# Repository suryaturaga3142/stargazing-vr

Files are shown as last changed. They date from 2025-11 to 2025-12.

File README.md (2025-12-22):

# Stargazer VR

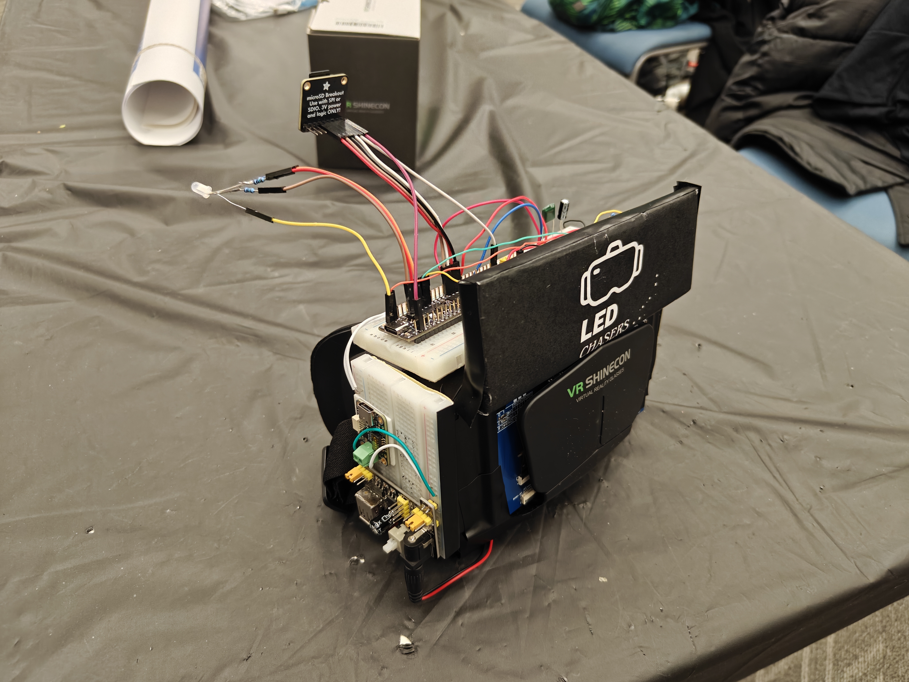
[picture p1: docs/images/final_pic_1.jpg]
Project Banner / Hero Image

*A high-performance, standalone VR headset powered by the RP2350 that renders real-time star constellations based on precise geolocation and orientation.*

---

## 📖 Introduction

Light pollution is a problem not many people talk about. We wanted to shed light on this issue (pun intended), so we decided to build a VR headset that let the user see the night sky at the comfort of their home. 

This project is a wearable headset with an RP2350 microcontroller and two 3.5" TFT LCD displays to display stars and constellations in the sky, in the direction of the viewer sight. It uses a BNO085 IMU to track the user movements, a NEO-M10 GPS module to obtain present location, date, and time, and an SD Card to store a large catalog of star location data in a binary file.

### ⭐ Spotlight

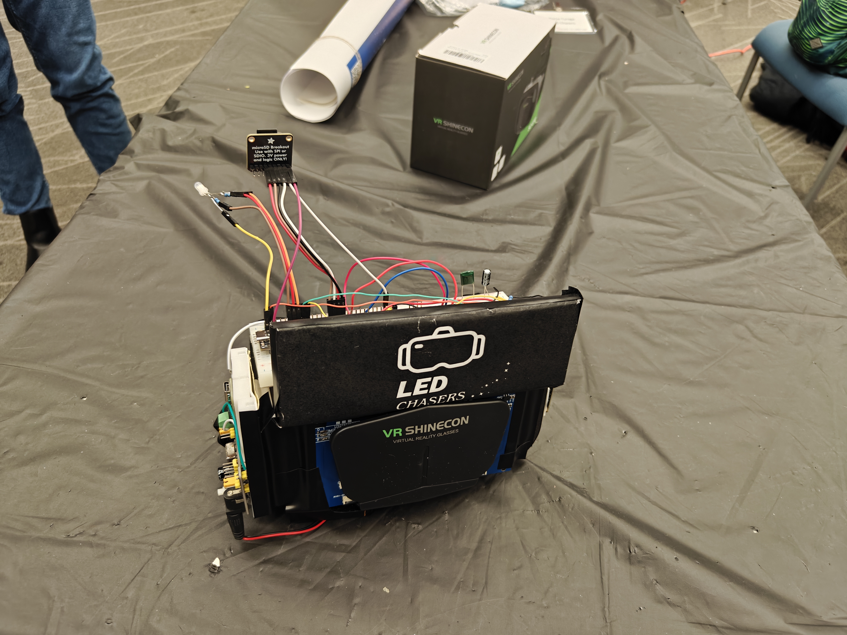
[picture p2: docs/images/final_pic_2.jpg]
Spotlight 1

*VR Headset assembled with a case, breadboards, and standard parts.*

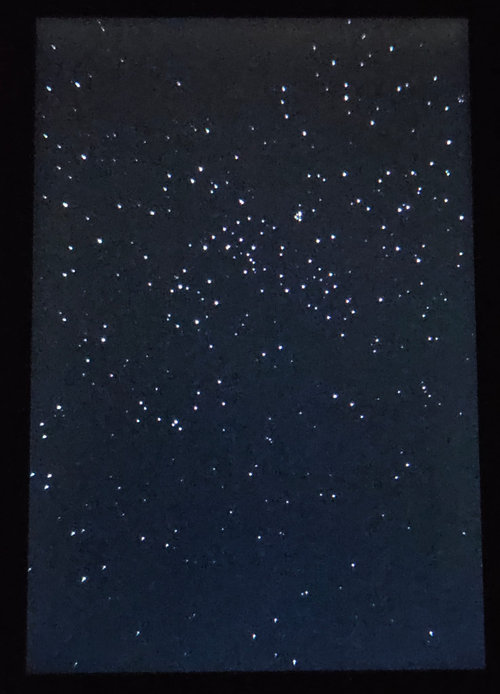
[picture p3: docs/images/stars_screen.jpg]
Spotlight 2

*View from a single screen during operation.*

Full View (https://youtu.be/E_Z8thj5-Y4?si=hsxMM6rmYNDNSfJs)

*360 Degree View of the Headset*

---

## 📑 Table of Contents

Our Story

- [Features](#-features)
- [Instructions for Usage](#-instructions-for-usage)
- [Software Developement](#-software-development)
  - [The Rendering Pipeline](#-the-rendering-pipeline)
  - [Side Quest 1: Scripting](#-side-quest-1-scripting)
  - [Optimizations](#-optimizations)
- [Hardware Building](#-hardware-building)
  - [The Physical Design](#-the-physical-design)
  - [So many issues!](#-so-many-issues)
  - [Side Quest 2: PCB Design](#-side-quest-2-pcb-design)
  - [Putting it all together](#-putting-it-all-together)
- [Closing Thoughts](#-closing-thoughts)

## 🚀 Features

The headset runs on a standard 9V battery, has two 3.5" TFT LCDs that display stars in front of the user with a 100 degree FOV. A single RGB LED is used to indicate the state of the VR Headset: booting, running, paused, critical error, etc. There are 3 buttons used to control the headset program flow. The Tare button recalibrates the IMU to face true North, the GPS toggle button switches between using real time GPS data and an in-built location and time (Purdue J2000), and the Pause/Play button does exactly that.

A single microSD card containing the required binary file format of star data can be inserted. Upon startup, this data is loaded into the RAM and processed. The catalog is limited to 15,000 stars. To produce the bin file, see [process_fits.py](data/scripts/process_fits.py), a script written to convert an fit file into the needed bin file.

The LCD Displays (ILI9486) as well as the microSD Card are controlled using SPI. The IMU (BNO085) is communicated with using I2C, more specifically SHTP. Finally, the GPS Module (Neo-M10) uses UART to transmit NMEA sentences.

---

Demo Video 1 (https://youtu.be/3412y5BKB1g?si=uu_Z9wU7jyXM4vg-)

*A short demonstration of the Headset working.*

Demo Video 2 (https://youtu.be/89O6f0i35UU?si=O_-78V77JQVSeXiZ)

*A demonstration of the UI of the headset.*

---

## 📃 Instructions for Usage

If wiring up on a breadboard, refer to the KiCad schematic for exact resistor values to use for the RGB LED, and connections to configure the IMU in I2C mode. Everything else works as it should assuming the use of breakout boards. Any standard LDO can be used to provide the 5V supply from the 9V battery. 

> [!WARNING]
> Do not connect a 3V3 output of your MCU to the LCDs! SST drivers have boost converters in them (as you should if you're implementing your own driver) and the current draw from 2 LCDs is too much current draw. You need a seperate regulator to provide external 3V3 from your 9V external.

If you're using the PCB, it's a plug and play. It needs the Adafruit BNO085 IMU breakout board (they were out of stock when this was designed). The PCB also makes use of 16 bit 8080 for the displays, making it significantly faster. Instead of a 9V battery, it will need a LiPo battery rated for above 1A. It can be charged with a wall charger, and programmed using a Pico probe.

---

## 🖥️ Software Development

We started with the software. Before wiring anything up, we began testing our design flow of using interrupts for timers, PWM, and GPIO. Then we went on to the more complex aspects like the communication with peripherals.

### 🚄 The Rendering Pipeline

The critical path is IMU to display, and it runs at 200Hz. The IMU generates in interrupt, which triggers main to read data, process it, find the final rotation, generate the star list, and draw/erase the display. Everything else, such as state setting, GPS reading, IMU taring, etc happen in the remaining 5ms between reads. 

The watchdog in the MCU is set to 1000ms and cleared every 200ms, so if there's a deadlock (especially an issue with the GPS), the system reboots.

### 🎬 Side Quest 1: Scripting

Python scripts were the method we used to get stuff done.

[process_fits.py](data/scripts/process_fits.py) is the most critical one. We used it to generate the needed binary file from a heavy fit file. Used ```astropy```.

[game_rot.py](data/scripts/game_rot.py) is more of an IMU debugging script. It reads game rotation vectors from the IMU and allows visualization of the data in 3D using ```pyqtgraph``` and ```PySide6```.

[see_stars.py](data/scripts/see_stars.py) is meant to test the sorting algorithm written to run on g++ in [test_buf_sort.cpp](data/scripts/test_buf_sort.cpp) by displaying the sorted data as patches on a 3D sphere. It's a neat visualization of how the data looks.

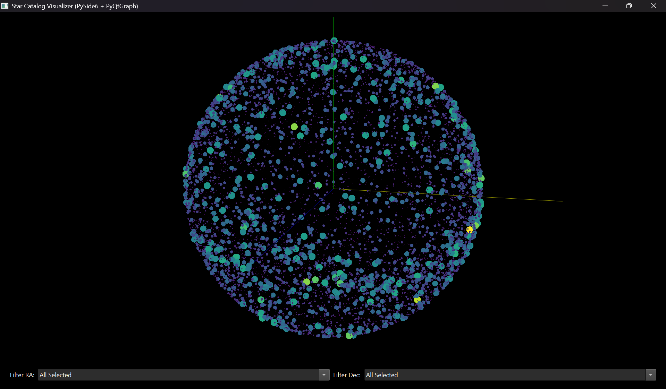
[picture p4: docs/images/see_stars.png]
Stars Visual

*Visualization of data sorted into 12 bins of Declination and 24 bins of Right Ascension.*

The remaining scripts were used to emulate the LCDs for debugging and calibrating purposes. They're more effective when you handwrite a small batch (~10) of test stars.

### 🪡 Optimizations

The first major optimization we used in this project was the use of quaternions for rotations. Instead of Euler angles, which are hard to visualize and are prone to gimbal lock, we used quaternions, which are 4D complex numbers, and are a completely neat set of mathematics immune to any edge cases. They literally describe rotations in the purest sense, with a single quaternion essentially behaving like a 3x3 rotation matrix meant to be applied on a 3x1 coordinate vector. Each of the 3 main factors - Location, Date/Time, and IMU vector - are all expressed as seperate quaternions, and combining them to obtain a single final rotation quaternions is akin to multiplying 3 matrices together!

$$ q_{final} = q_{IMU} \cdot q_{location} \cdot q_{time} $$

$$ v_{final} = q_{final} \cdot v_{J2000} \cdot q_{final}^{*} $$

Our next optimization was Spatial Culling, optimizing in what to do with this final rotation. Applying it to all stars only to then narrow down a 100 degree FOV would be far too expensive computationally. Instead, we applied the inverse rotation to the perspective vector, and then checked which set of stars could appear on screen. That's where the bin sorting came into play. The 288 patches were sorted based on RA and DEC, allowing easy access of patches to then apply the rotation to. 

Finally, we used double buffering to allow erasing of old stars and drawing of new ones together. Keeping this rate maxed out, it even created an unintentional twinkling effect of stars! It's not a bug, it's a feature.

---

## 🛠️ Hardware Building

While the code was being developed, stuff was getting wired up on the breadboard! Starting with the RGB LED, then moving to the IMU, GPS, SD Card, and finally, the displays. This was just the process of integration, of course. Everything software and hardware was being developed and tested slowly at the same time.

### The Physical Design

On the breadboard, there wasn't much to do. We simplified a lot of wiring by using breakout boards for all parts. Appropriate resistor sizes were chosen for the RGB LED and soldered. Everything else was just connected with regular wiring. The breadboard design was arguably the easiest part of this project. We got ourselves a 9V to breadboard supply board that provided the needed 5V and 3V3 supplies. That with a USB-C breakout was all we needed. Refer to [config.h](include/config.h) for exact connections for breadboarding. Remember, the PCB was different! Check the schematic for that.

### So many issues!

We initially tried to speed up graphics by using PIO to communicate with the LCDs through 16-bit 8080. Using long and noisy wires, this ended up being a bit of a mess.

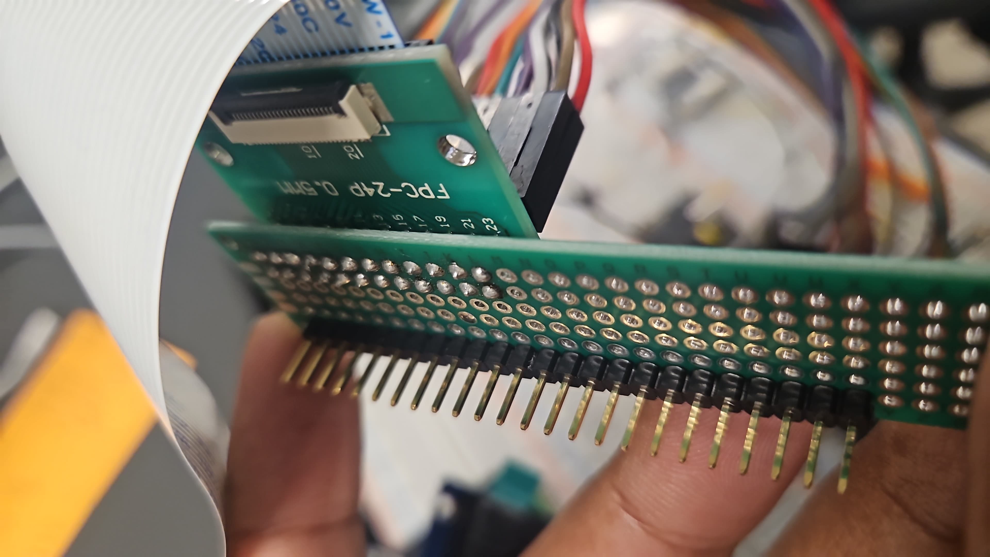
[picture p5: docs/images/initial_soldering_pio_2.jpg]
Parallel Wiring

*FPC connector to breadboard wire soldering*

Due to the noise in these wires and the precise timing requirements, we scrapped this idea after a lot of failed attempts, and moved back to SPI. The same issue happened to the microSD Card, where SDIO may not have been feasible due to the wiring size. Hence, both were moved back to SPI.

An interesting challenge faced was balancing timing with performance. What was the fastest we could go without messing up the visuals? How much gap did we give between render frames? And how much did we zoom into a patch? There were several calibration challenges that needed solving. And then there was the issue of making sure there was enough space on the board for all connections. [main.cpp](src/main.cpp) and [config.h](include/config.h) have the exact timings.

### Side Quest 2: PCB Design

Making the PCB took an all nighter. For all the files, check [pcb-stargazing](./pcb-stargazing/), which has the full KiCad 9.0 project. It uses the same RP2350B with the same set of parts. It's important to note that due to vendor shortage, the IMU was replaced with headers for the Adafruit breakout board for BNO085. Due to the requirements of moving the displays, 2 FPC connectors were installed at the edge of the PCB for displaying. Due to the noise requirements, the GPS module is connected with a JST connector, to prevent the antenna from catching noise. 

Finally, the device is programmed with the Pico Probe headers and powered by a rechargeable LiPo battery. The USB-C receptacle can either charge the battery during runtime, or power the device. Charging needs the supercharge switch enabled, and it has to be connected to a wall socket. Excess current draw will trigger a laptop polyfuse if you try charging. Fun side note, the PCB also has a breakout meant to attach into a breadboard to allow for easy parallel interfacing with a display using an FPC!

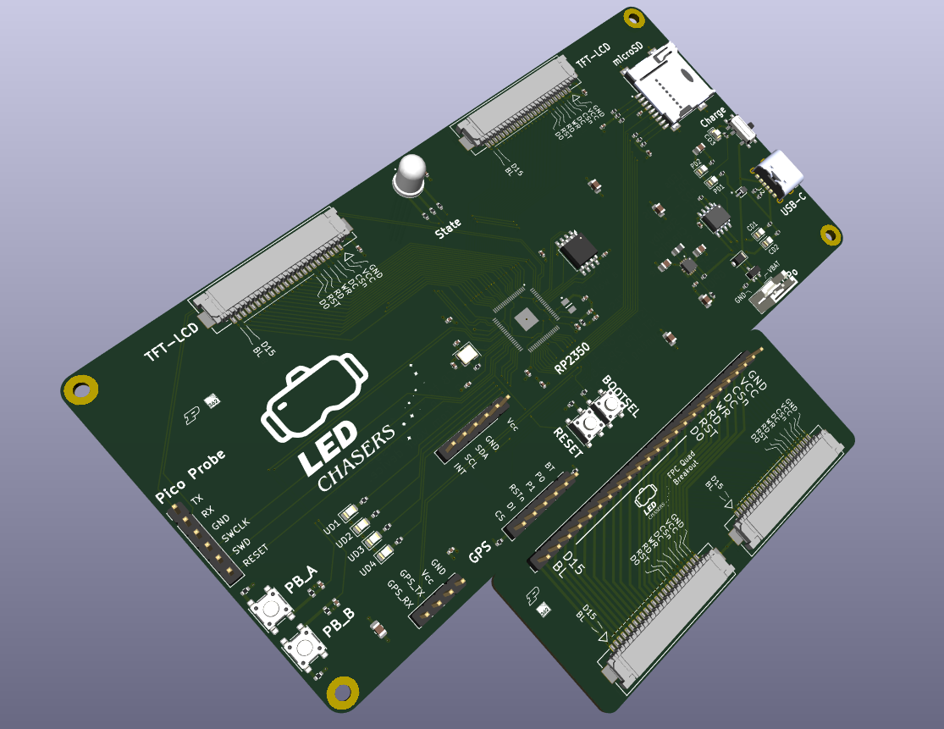
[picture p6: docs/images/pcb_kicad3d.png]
PCB 3D Model

*3D Model of the PCB that was built.*

### Putting it all together

Everything was held together with electrical tape. And it worked well! The occasional loose connection was annoying, but the project worked nevertheless. We had to end up using the breadboards as opposed to the PCB, though. That was a bit sad, but seeing the headset work was awesome!

---

## 📦 Closing Thoughts

Despite all the issues we faced, we were able to showcase our project at the Purdue University Spark Challenge in December 2025. Showing the project to friends and teachers alike was an unforgettable experience. 

Technically speaking, there's a good number of improvements that can be made. Small adjustments like adjusting x and z FOVs as well as star pixel designs are user choices. Speed optimizations can be made, too. Firstly, swapping out normal writing for DMA would significantly speed up LCD display drawing. So would a parallel interface and using the RP2350 dual core capabilities to seperate computations and rendering.

Thankfully, the project is really modular. Every file works independantly, and swapping out mechanisms is definitely a large area for improvement that can be achieved.

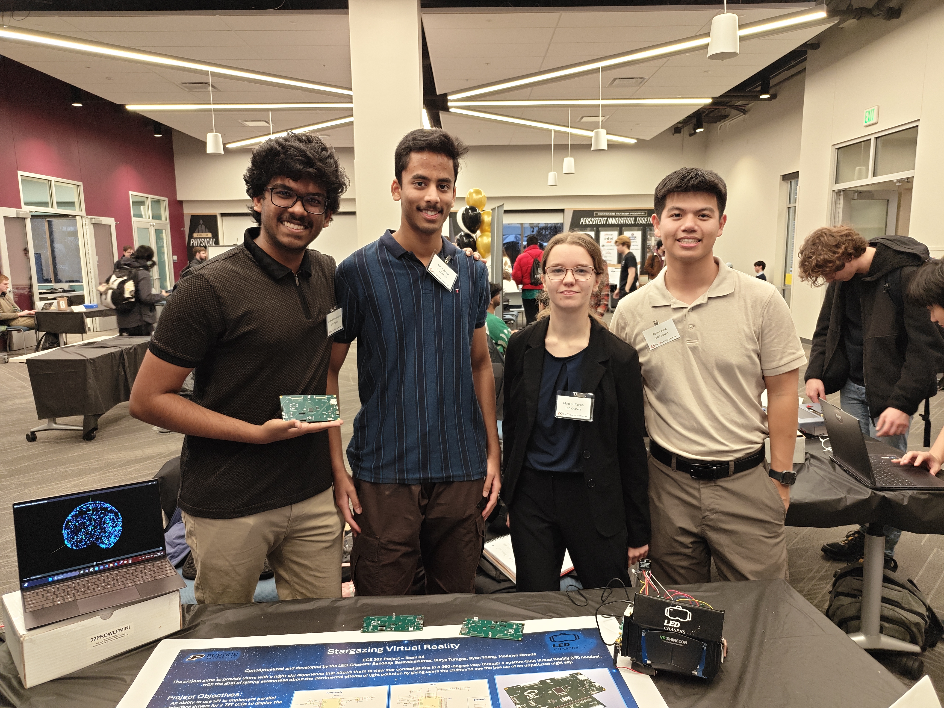
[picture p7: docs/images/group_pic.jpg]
Group Pic

*LED Chasers - (L to R) Sandeep Saravanakumar, Surya Turaga, Madelyn Zavada, Ryan Yoong*

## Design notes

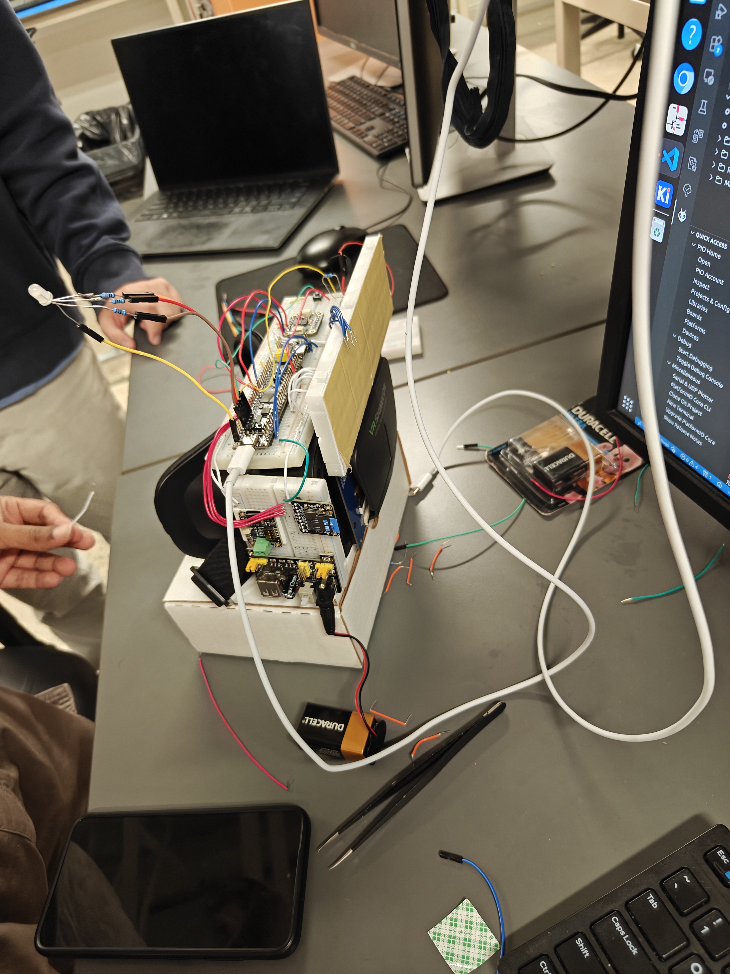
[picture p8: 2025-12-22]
docs/images/final_integration_2.jpg

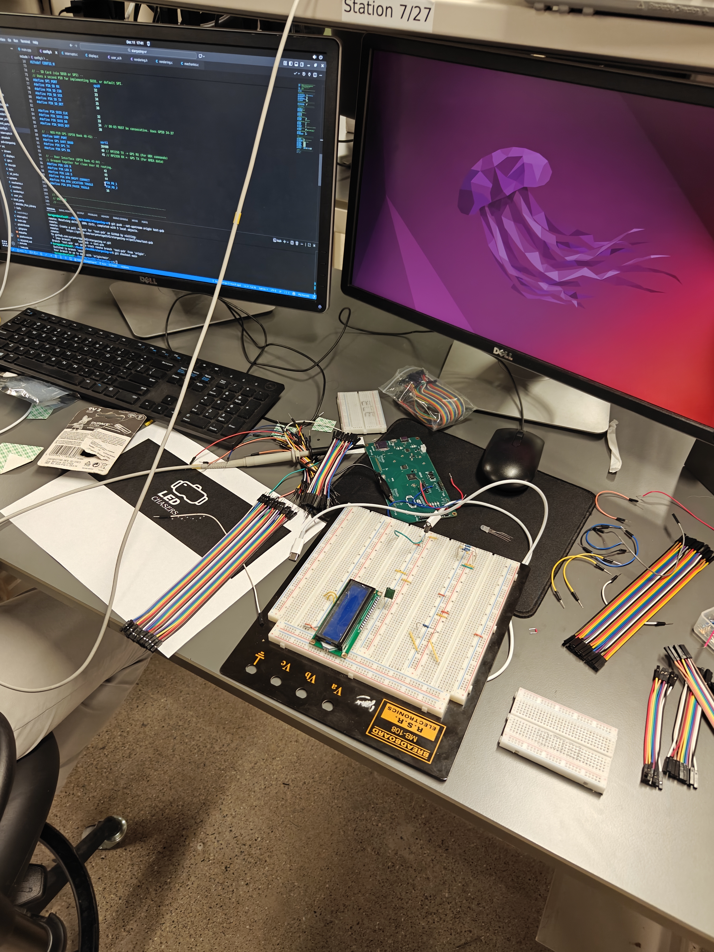
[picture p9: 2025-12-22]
docs/images/final_integration.jpg

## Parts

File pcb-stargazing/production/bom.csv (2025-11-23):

Designator | Footprint | Quantity | Value | LCSC Part #
C1, C12, C14, C2, C23, C3, C5, C7 | 0805 | 8 | 10u | C1713
C15, C16 | 0402 | 2 | 15p | C1548
C17, C18, C20, C21 | 0402 | 4 | 4.7u | C76995
C19, C22, C24, C25, C26, C27, C28, C29, C30, C31, C32, C33, C34, C35 | 0402 | 14 | 100n | C1525
C4 | 0402 | 1 | 10u | C15525
C6 | 0402 | 1 | 1u | C52923
C9 | 0402 | 1 | 1n | C1523
CD1, PD2, UD3 | 0805 | 3 | GREEN | C2297
CD2, UD2 | 0805 | 2 | YELLOW | C2296
CD3, UD4 | 0805 | 2 | BLUE | C2293
CR1 | CR_60JFILM_STM | 1 | BAT60JFILM | C133103
D1 | LED_QBL8RGB60D0-2897 | 1 | QBL8RGB60D0-2897 | C330749
D2 | D_SOD-123F | 1 | BZT52B5V1 | C78479
J1 | JST_EH_B2B-EH-A_1x02_P2.50mm_Vertical | 1 | JST 1x02 | C160262
J10 | PinHeader_1x24_P2.54mm_Vertical | 1 | Conn_01x24_Pin | C7430380
J11, J12, J5, J6 | CON_522072460_MOL | 4 | 522072460 | C5409332
J13, J14, J7, J8 | CON_522712469_MOL | 4 | 522712469 | C5409332
J15, J16 | PinHeader_1x06_P2.54mm_Vertical | 2 | Conn_01x06_Pin | C37208
J2 | GCT_USB4125-GF-A_REVA2 | 1 | USB4125-GF-A_REVA2 | C3151650
J3 | PinHeader_1x04_P2.54mm_Vertical | 1 | Conn_01x04_Pin | C22438287
J4 | GCT_MEM2075-00-140-01-A | 1 | MEM2075-00-140-01-A | C3029735
J9 | PinHeader_1x06_P2.54mm_Vertical | 1 | Conn 1x06_Pin | C37208
L1 | 0805 | 1 | 1.5u | C139220
L2 | AOTAB201610S3R3101T | 1 | 3.3u | C42411119
PD1, UD1 | 0805 | 2 | RED | C84256
Q1 | SOT-23 | 1 | DMP3099L | C2940610
R1, R14, R28 | 0402 | 3 | 5.1k | C25905
R10, R11, R12, R16, R18, R2, R33, R37, R6, R8, R9 | 0402 | 11 | 10k | C25744
R17, R21, R24, R25, R27, R29, R31, R34, R35 | 0402 | 9 | 1k | C11702
R19, R30 | 0402 | 2 | 3k | C25559
R22 | 0402 | 1 | 1.2k | C25862
R23 | 0402 | 1 | 1M | C26083
R26 | 0402 | 1 | 33 | C25105
R3 | 0402 | 1 | 68 | C25131
R32 | 0402 | 1 | 2k | C4109
R36 | 0402 | 1 | 510 | C25123
R4 | 0402 | 1 | 470 | C25117
R5 | 0402 | 1 | 22 | C25092
R7 | 0402 | 1 | 100k | C25741
SW1 | SW_SPDT_PCM12 | 1 | SW_SPDT | C221841
SW2 | SW_SPST_PTS647_Sx38 | 1 | BOOTSEL | C2689502
SW3 | SW_SPST_PTS647_Sx38 | 1 | RESET | C2689502
SW4 | SW_SPST_PTS647_Sx38 | 1 | LEFT | C2689502
SW5 | SW_SPST_PTS647_Sx38 | 1 | RIGHT | C2689502
U2 | SOIC-8-1EP_3.9x4.9mm_P1.27mm_EP2.41x3.3mm_ThermalVias | 1 | TP4056-42-ESOP8 | C16581
U3 | QFN50P250X250X100-12N | 1 | TPS63051RMWR | C139412
U4 | QFN40P1000X1000X90-81N-D | 1 | RP2350_80QFN | C42415655
U5 | SOIC-8_5.3x5.3mm_P1.27mm | 1 | W25Q128JVS | C97521
Y2 | Crystal_SMD_3225-4Pin_3.2x2.5mm | 1 | ABM8-272-T3 | C20625731

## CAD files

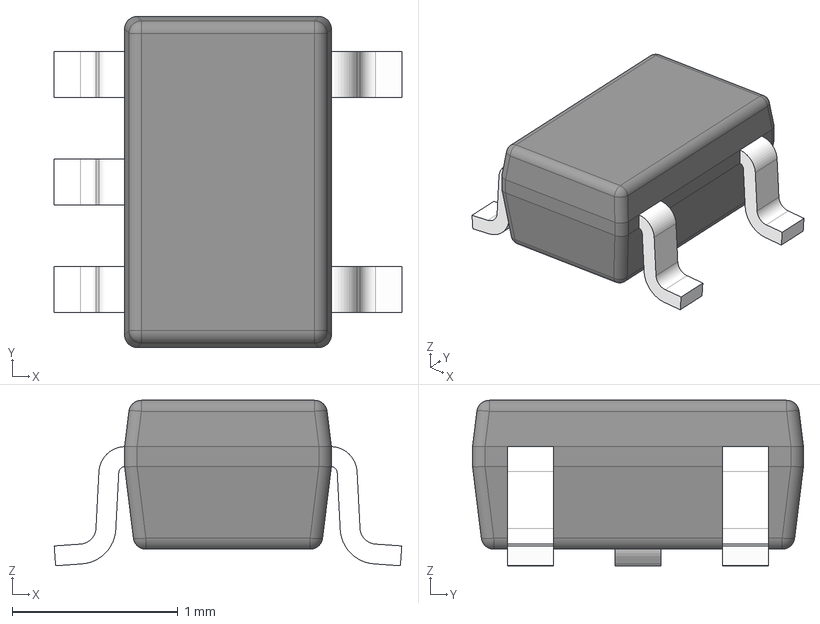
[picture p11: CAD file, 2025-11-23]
pcb-stargazing/footprints/SN74AUP1T17DCKR/DCK0005A.stp
2.10 x 2.00 x 1.00 mm
BODY-SOT
LEAD-SOT x 5
PIN1-ID

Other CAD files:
pcb-stargazing/3dmodels/BAT60JFILM.STEP
pcb-stargazing/footprints/BAT60JFILM/CR_60JFILM_STM.step
pcb-stargazing/footprints/W25Q16JVUXIQ_TR/USON-8_UX_2x3x0p6_WIN.step
pcb-stargazing/3dmodels/SFW24R4STE1LF.STEP
pcb-stargazing/3dmodels/USB4125-GF-A--3DModel-STEP-56544.STEP
pcb-stargazing/3dmodels/MEM2067-02-180-00-A--3DModel-STEP-56544.STEP
pcb-stargazing/3dmodels/IN-P55TATRGB--3DModel-STEP-56544.STEP
pcb-stargazing/3dmodels/TP4056-42-ESOP8--3DModel-STEP-56544.STEP
pcb-stargazing/3dmodels/ABM8-272-T3.step
pcb-stargazing/3dmodels/USB4110GFA.step
pcb-stargazing/3dmodels/QBL8RGB60D0-2897.step
pcb-stargazing/3dmodels/RP2350_QFN80.step
pcb-stargazing/3dmodels/SM06B-GHS-TB.step
pcb-stargazing/3dmodels/B4B-PH-K--3DModel-STEP-56544.STEP
pcb-stargazing/3dmodels/BM06B-GHS-TBT_LF__SN__N_.step
pcb-stargazing/3dmodels/BNO085.step
pcb-stargazing/3dmodels/BNO085--3DModel-STEP-510211.STEP
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

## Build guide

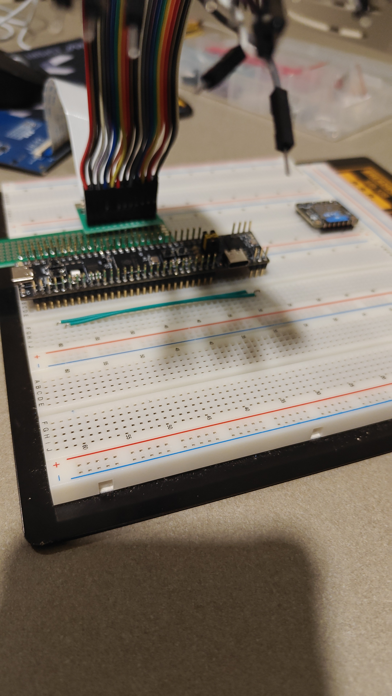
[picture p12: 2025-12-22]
docs/images/parallel_wiring_8080_lcd.jpeg

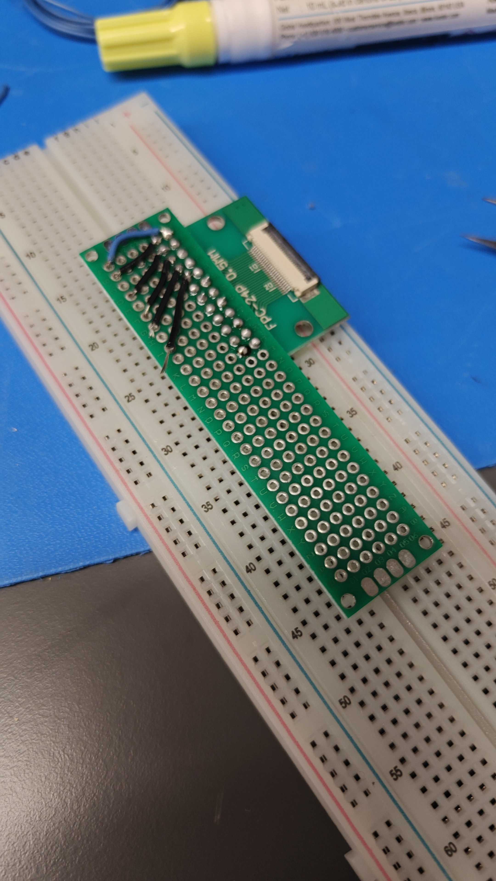
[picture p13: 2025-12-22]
docs/images/initial_soldering_pio.jpeg

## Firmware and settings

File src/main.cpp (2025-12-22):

/*******************************************************************************
 * @file        main.cpp
 * @brief       Implements the functionality for the main module.
 * @details     This is the main file for the project.
 * 
 * @author      LED Chasers
 * @date        2025-10-14
 * 
 * @note        This module is designed to be the main module to drive everything.
 *              Don't put interrupts here. Initialize everything, go through the
 *              startup process, and execute the lowest level non critical blocking
 *              tasks that potentially cause priority blocking when in handlers.
 * 
 * @copyright   Copyright (c) 2025, LED Chasers. All rights reserved.
 ******************************************************************************/

/* ----------------------------- Private Includes --------------------------- */
#include <stdio.h>
#include <stdint.h>
#include <string.h>

#include "pico/stdlib.h"

#include "hardware/gpio.h"
#include "hardware/dma.h"
#include "hardware/irq.h"
#include "hardware/spi.h"
#include "hardware/i2c.h"
#include "hardware/sync.h"
#include "hardware/watchdog.h"

#include "structs.h"
#include "config.h"
#include "interrupts.h"

#include "display.h"
#include "gps.h"
#include "imu.h"
#include "sd_card.h"

#include "mechanics.h"
#include "monitor.h"
#include "rendering.h"
#include "user_ui.h"


int main()
{

    // PHASE 1: Power On Setup
    stdio_init_all();
    user_ui_init();
    printf("Starting up...\r\n");

    // Alerts if rebooted
    if (watchdog_caused_reboot()) {
        printf("Watchdog caused a reboot!\r\n");
        g_use_gps_location = false; // Switch off in case GPS reading caused the timeout
        user_ui_set_state(LED_STATE_REBOOTED);
        sleep_ms(2000);
        user_ui_set_state(LED_STATE_BOOTING);
    }
    // Setup watchdog with timeout during startup procedures. Pet it during long processes.
    watchdog_enable(WATCHDOG_INIT_TIMEOUT_MS, true);

    // PHASE 2: Connectivity Check
    printf("Initializing peripherals...\r\nSearching SD Card...\r\n");
    bool sd_alive = sd_init();

    // If not present, run a 10 second warning while polling sd_check()
    if (!sd_alive) {
        printf("No SD Card detected! Please insert one.\r\nWaiting...\r\n");
        user_ui_set_state(LED_STATE_SD_LOADING);
        for (int i = 0; i < 100; i++) {
            sleep_ms(100);
            watchdog_update();
            sd_alive = sd_check();
            if (sd_alive) break;
        }
    }
    // If a timeout occured the error state is entered.
    if (!sd_alive) {
        watchdog_disable();
        printf("Error: SD Card Connectivity Timeout Occured. SD Card missing / unresponsive.\r\nPlease insert working SD Card and restart.\r\n");
        user_ui_set_state(LED_STATE_ERR_CRITICAL);
        for(;;) {
            __wfi();
        }
    }
    user_ui_set_state(LED_STATE_BOOTING);
    watchdog_update();

    printf("SD Card alive!\r\nChecking IMU...\r\n");
    bool imu_connected = imu_init();     // Check IMU presence and initialize, set to true for sd testing, set back to imu_init() otherwise 
    if (imu_connected) watchdog_update();
    else {
        watchdog_disable();
        printf("Error: IMU not detected!\r\nPlease check connections and restart.\r\n");
        user_ui_set_state(LED_STATE_ERR_CRITICAL);
        for (;;) {
            __wfi();
        }
    }

    printf("IMU detected!\r\nStarting LCD...\r\n");
    display_init();

    watchdog_update();

    // PHASE 3: Heavy Lifting (PET THE WATCHDOG MANY TIMES!)
    printf("Initialized LCD!\r\nMounting & Bulk Reading SD Card...\r\n");
    bool data_loaded = sd_load_data(); // Mount and bulk read the SD card data
    if (data_loaded) watchdog_update();
    else {
        watchdog_disable();
        printf("Error: Unable to read SD Card. Check if stars.bin is present & correct?\r\n");
        user_ui_set_state(LED_STATE_ERR_CRITICAL);
        for (;;) {
            __wfi();
        }
    }
    printf("Data Read!\r\nDisabling card & sorting data...\r\n");
    disable_sdcard();

    watchdog_update();
    sd_buf_sort();  // Sorts data in 3 pass algorithm


    watchdog_update();
    printf("SD Card disabled & data sorted!\r\nInitializing GPS (This will take time)...\r\n");
    
    bool gps_fixed = gps_init();
    watchdog_disable();
    
    if (gps_fixed && g_use_gps_location && g_latest_gps_data.is_valid) {
        printf("GPS Lock found! Starting rendering...\r\nEnjoy!!\r\n");
        printf("Data: %d \r\nLat: %f \r\nLon: %f \r\nDate: %d/%d/%d \r\nTime: %d:%d:%d \r\n", 
            g_latest_gps_data.is_valid, g_latest_gps_data.latitude, g_latest_gps_data.longitude, 
            g_latest_gps_data.time.day, g_latest_gps_data.time.month, g_latest_gps_data.time.year,
            g_latest_gps_data.time.hour, g_latest_gps_data.time.minute, g_latest_gps_data.time.second);
        user_ui_set_state(LED_STATE_RUN);
    }
    else {
        printf("No GPS Lock found / avoiding due to reboot. Starting with no location fix.\r\nEnjoy!!\r\n");
        user_ui_set_state(LED_STATE_RUN_NO_FIX);
    }
    
    // PHASE 4: Handover process
    // Reconfigure watchdog for main loop checking and setup monitoring supervisor
    irq_set_priority(IO_IRQ_BANK0  , 0x10);   // IMU INT and PB
    irq_set_priority(TIMER0_IRQ_1  , 0x20);   // GPS data
    irq_set_priority(PWM_IRQ_WRAP_0, 0x30);   // RGB LED State
    irq_set_priority(TIMER0_IRQ_0  , 0x40);   // Monitor Checkin
    monitor_init();
    watchdog_enable(WATCHDOG_TIMEOUT_MS, true);

    // Loop
    while (true) {

        // Sleep until an interrupt fires
        __wfi();
        // Awake now bc interrupt fired. Do the events in order of priority.
        
        // If the read flag is turned on, the IMU is automatically read using the SHTP protocol and updated in the background.
        if (imu_check_and_read()) {
            // printf("Game: %f %f %f %f\r\n", 
            //        g_latest_imu_data.orientation.x, g_latest_imu_data.orientation.y, g_latest_imu_data.orientation.z, g_latest_imu_data.orientation.w);
            monitor_checkin(SYS_MODULE_IMU);

            run_main_render();

            monitor_checkin(SYS_MODULE_DISPLAY);
        }

        // Whenever this is called, the system CAN lag for at most GPS_TIMEOUT_MS. A small freeze will be noticed whenever the background GPS update task is carried out.
        // This is because GPS update and rendering is done in main, and only one can occur at any given point! No, we did not use both cores lol.
        // This lag is the cost of running precalculations to avoid massive rendering times.
        if (g_use_gps_location && gps_check_and_read() && g_latest_gps_data.is_valid) {

            /*
            printf("Data: %d \r\nLat: %f \r\nLon: %f \r\nDate: %d/%d/%d \r\nTime: %d:%d:%d \r\n", 
                g_latest_gps_data.is_valid, g_latest_gps_data.latitude, g_latest_gps_data.longitude, 
                g_latest_gps_data.time.day, g_latest_gps_data.time.month, g_latest_gps_data.time.year,
                g_latest_gps_data.time.hour, g_latest_gps_data.time.minute, g_latest_gps_data.time.second);
            */
            Qfix_t Qfix_latest;
            Qfix_latest.loc   = mech_location_to_q(g_latest_gps_data.latitude, g_latest_gps_data.longitude);
            Qfix_latest.time  = mech_time_to_q(mech_utc_to_sidereal(g_latest_gps_data.time));
            Qfix_latest.total = mech_product_q(Qfix_latest.loc, Qfix_latest.time);
            Qfix_last = Qfix_latest;
        }
        monitor_checkin(SYS_MODULE_GPS);

        if (g_play_screen && g_use_gps_location) {
            if (g_latest_gps_data.is_valid) user_ui_set_state(LED_STATE_RUN);
            else                            user_ui_set_state(LED_STATE_RUN_NO_FIX);
        }
        else if (g_play_screen) user_ui_set_state(LED_STATE_RUN_J2000);
        else                    user_ui_set_state(LED_STATE_PAUSED);

        if (g_drift_correct_request) {
            user_ui_set_state(LED_STATE_DRIFT_CONFIRM); // It will get overwritten fast so it's just a blink
            imu_recenter_yaw();
            monitor_checkin(SYS_MODULE_IMU);
            g_drift_correct_request = false;
        }
        if (g_location_toggle_request) {
            g_use_gps_location = !g_use_gps_location;
            g_location_toggle_request = false;
        }
        // Pause toggle request needs handling in rendering loop.

        monitor_checkin(SYS_MODULE_MAIN);
    }

    // Should never reach here.
    for(;;) __wfi();

    return 0;
}

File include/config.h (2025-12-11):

/*******************************************************************************
 * @file        config.h
 * @brief       Set of project configuration variables and definitions.
 * @details     This header file will define all variables related to 
 *              controlling the software before flashing.
 * 
 * @see         config.c for implementation details.
 * 
 * @author      LED Chasers
 * @date        2025-10-14
 * @version     1.0
 ******************************************************************************/

#ifndef CONFIG_H
#define CONFIG_H

//------------------------------------------------------------------------------
// SYSTEM TIMING CONSTANTS
//------------------------------------------------------------------------------

#define TARGET_REFRESH_RATE_HZ          200
#define TARGET_REFRESH_PERIOD_MS        (1000 / TARGET_REFRESH_RATE_HZ)

#define GPS_CORRECTION_INTERVAL_MIN     5
#define GPS_INIT_TIMEOUT_MS             10000
#define GPS_TIMEOUT_MS                  1000

#define WATCHDOG_INIT_TIMEOUT_MS        20000
#define WATCHDOG_TIMEOUT_MS             5000
#define WATCHDOG_SUPERVISOR_INTERVAL_MS 500

#define SD_CARD_INIT_HZ                 400000
#define SD_CARD_READ_HZ                 5000000

//------------------------------------------------------------------------------
// STAR CATALOG & CULLING CONSTANTS
//------------------------------------------------------------------------------

#define STAR_CATALOG_SIZE_MAX           10000
#define SKY_PATCH_RA_DIVISIONS          24
#define SKY_PATCH_DEC_DIVISIONS         12

//------------------------------------------------------------------------------
// PERIPHERAL CONFIGURATION
//------------------------------------------------------------------------------

// -- ILI9486 Displays (GPIO 9-13) --
// Written with SPI.
#define LCD_PORT    spi1
#define PIN_LCD_CS  9
#define PIN_LCD_SCK 10 // SPI1 SCK
#define PIN_LCD_SDI 11 // SPI1 TX
#define PIN_LCD_DC  12
#define PIN_LCD_RST 13

// -- In Built Zone (GPIO 21-26) --
// Connected to Proton board PBs and LEDs.
#define PIN_PB_1  21
#define PIN_PB_2  26
#define PIN_LED_1 22
#define PIN_LED_2 23
#define PIN_LED_3 24
#define PIN_LED_4 25

// -- BNO085 IMU (GPIO Bank 27-30) --
// Grouped together for clean I2C routing.
#define I2C_PORT                        i2c0
#define IMU_I2C_ADDR                    0x4A
#define PIN_IMU_SDA                     28
#define PIN_IMU_SCL                     29
#define PIN_IMU_INT                     30  // Interrupt pin
#define PIN_IMU_RST                     31  // Reset pin

// -- SD Card (via SDIO or SPI) --
// Uses a second PIO for implementing SDIO, or default SPI.
#define SPI_PORT                        spi0
#define PIN_SD_RX                       32
#define PIN_SD_CSN                      33
#define PIN_SD_SCK                      34
#define PIN_SD_TX                       35
#define PIN_SD_DET                      38

#define PIN_SDIO_CLK                    32
#define PIN_SDIO_CMD                    33
#define PIN_SDIO_D0                     34  // D0-D3 MUST be consecutive. Uses GPIO 34-37
#define PIN_SDIO_DET                    38

// -- NEO-M10 GPS (GPIO Bank 40-41) --
#define UART_PORT                       uart1
#define GPS_UART_BAUD                   38400
#define PIN_GPS_TX                      40 // RP2350 TX -> GPS RX (For UBX commands)
#define PIN_GPS_RX                      41 // RP2350 RX <- GPS TX (For NMEA data)

// -- User Interface (GPIO Bank 42-44) --
// Grouped together for clean User UI routing.
#define PIN_LED_R                       42
#define PIN_LED_B                       43
#define PIN_LED_G                       44
#define PIN_BTN_DRIFT_CORRECT           PIN_PB_1
#define PIN_BTN_LOCATION_TOGGLE         PIN_PB_2
#define PIN_BTN_PAUSE_TOGGLE            16


//------------------------------------------------------------------------------
// USER UI
//------------------------------------------------------------------------------
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

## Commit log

2025-10-07 Wrote convert_UT_to_GMST() and convert_GMST_to_LST() functions
    Functions to convert solar time to sidereal time for current location
2025-11-12 setup folder
    [pcb-stargazing.kicad_pcb, pcb-stargazing.kicad_sch]
2025-11-12 added all extra setups
    [CR_60JFILM_STM.step, DCK0005A.stp, RP2350_QFN80.step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]
2025-11-12 started schem
    [DebugProbe.kicad_sch, pcb-stargazing.kicad_sch]
2025-11-12 about to change a lot
    [pcb-stargazing.kicad_sch]
2025-11-12 added parts and smol changes
    [0522072460.stp, B4B-PH-K--3DModel-STEP-56544.STEP, BNO085--3DModel-STEP-510211.STEP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]
2025-11-12 worked more almost done schem
    [DebugProbe.kicad_sch, PowerSupply.kicad_sch, TPS63051RMWR.step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]
2025-11-13 almost done with schem:
    [Peripherals.kicad_sch, PowerSupply.kicad_sch, SM06B-GHS-TB.step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]
2025-11-13 done schematic, assignemtn now
    [Peripherals.kicad_sch, PowerSupply.kicad_sch, pcb-stargazing.kicad_sch]
2025-11-13 pcb started
    [Peripherals.kicad_sch, PowerSupply.kicad_sch, pcb-stargazing.kicad_pcb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]
2025-11-13 schem and linking final
    [0522712469.stp, pcb-stargazing.kicad_pcb, pcb-stargazing.kicad_sch]
2025-11-13 pcb in progress 3d done
    [BAT60JFILM.STEP, BNO085.step, IN-P55TATRGB--3DModel-STEP-56544.STEP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]
2025-11-13 rmed useless
    [Peripherals.kicad_sch, PowerSupply.kicad_sch]
2025-11-13 clearance fix
    [pcb-stargazing.kicad_pcb, pcb-stargazing.kicad_sch]
2025-11-14 almost done placing
    [pcb-stargazing.kicad_pcb, pcb-stargazing.kicad_sch]
2025-11-14 100 connections left
    [pcb-stargazing.kicad_pcb, pcb-stargazing.kicad_sch]
2025-11-14 5 connections left
    [pcb-stargazing.kicad_pcb]
2025-11-17 about to change stuff again
    [pcb-stargazing.kicad_pcb]
2025-11-17 wokring schem
    [pcb-stargazing.kicad_sch]
2025-11-18 working on bom
    [BM06B-GHS-TBT_LF__SN__N_.step, bom.csv, breakout.kicad_sch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]
2025-11-18 schem done fs
    [MEM2075-00-140-01-A.step, breakout.kicad_sch, pcb-stargazing.kicad_sch]
2025-11-18 pcb resetting
    [pcb-stargazing.kicad_pcb]
2025-11-18 pcb ongoing once again
    [bom.csv, breakout.kicad_sch, designators.csv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]
2025-11-19 getting there
    [pcb-stargazing.kicad_pcb, pcb-stargazing.kicad_sch]
2025-11-19 pcb done mouse bites and all left
    [breakout.kicad_sch, pcb-stargazing.kicad_pcb, pcb-stargazing.kicad_sch]
2025-11-19 ready for the cutting
    [pcb-stargazing.kicad_pcb]
2025-11-20 rmed useless csv
    [pcb-stargazing.csv]
2025-11-20 production files are p good
    [bom.csv, designators.csv, pcb-stargazing.kicad_pcb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]
2025-11-20 defo donee
    [pcb-stargazing.kicad_pcb, positions.csv]
2025-11-20 edge fixed
    [pcb-stargazing.kicad_pcb]
2025-11-21 initial breakoff
    [pcb-stargazing.kicad_pcb]
2025-11-21 ready for round 2
    [QBL8RGB60D0-2897.step, SFW24R4STE1LF.STEP, USB4125-GF-A--3DModel-STEP-56544.STEP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]
2025-11-21 repaced stuff
    [ABM8-272-T3.step, breakout.kicad_sch, pcb-stargazing.kicad_pcb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]
2025-11-21 ready again
    [bom.csv, pcb-stargazing.kicad_pcb, positions.csv]
2025-11-21 ready again prbs
    [pcb-stargazing.kicad_pcb]
2025-11-25 added imu files
2025-11-27 IMU integrated in startup
2025-11-27 imu works perfectt
2025-11-27 done with imu corr request
2025-12-02 fixed cpp to c bugs
    [main.cpp, sd_card.c, vr_sim.py]
2025-12-22 pcb pic added
